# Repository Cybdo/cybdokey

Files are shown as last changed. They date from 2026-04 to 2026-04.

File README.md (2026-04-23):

# CybdoKey
A RP2354 based usb hardware authentication key, or anything else you can write firmware for ;)

render showing front and back of cybdokey

Cybdokey was made because yubikeys are too expensive and all the other options, including picofido on other devboards, were clunky. the user interaction button was tiny and hard to press, and depending on the board it was too big and/or needed an extra cable. Cybdokey was made to be a polished, compact FIDO key with capacative touch support.

**Note:** `bom.csv` is the LCSC parts list with working liks, whilst `overall-bom.csv` is an estimate of the overall project cost

## Zine Page / Poster

pdf in `assets/zine/Zine page.pdf`

Zine page

## Features
- RP2354-based development board
- Stacked 2MB flash storage
- onboard USB-A connector
- Capacative touch pad with shine-through red and blue LEDs
- exposed 3V3, GND, RESET and BOOTSEL
- 2 keyring/accessory mount holes
- Hand-solderable (in theory)
- tiny form factor!
render showing the backside of cybdokey

## Usage

Simply plug Cybdokey into your computer's USB-A port, and it will function similar to a yubikey. Passkeys and OTPs can be stored on it, and it supports human presence detection using the capacative touch pad. LED signals are identical to that of any other pico-fido key.

## Schematics


## PCB

|Front|Back|
|---|---|
| | |

## Firmware

See [https://github.com/cybdo/cybdokey-fw](https://github.com/cybdo/cybdokey-fw) for FIDO key firmware.

Firmware can be flashed on first boot, or by shorting the BOOTSEL jumper on the left side of the crystal, diagonally underneath the MCU, before booting.

CybdoKey is also compatiable with anything written for a RP2350/RP2354.

## Credits and Acknowledgements

 - [KiCad](https://www.kicad.org)
 - [Hack Club Fallout](https://fallout.hackclub.com)
 - [pcb2blender](https://github.com/30350n/pcb2blender)
 - [Blender](https://blender.org)
 - [MicroKey](https://github.com/Badbird5907/microkey)
 - [Pico FIDO](https://github.com/polhenarejos/pico-fido), forked to make [CybdoKey firmware](https://github.com/cybdo/cybdokey-fw)

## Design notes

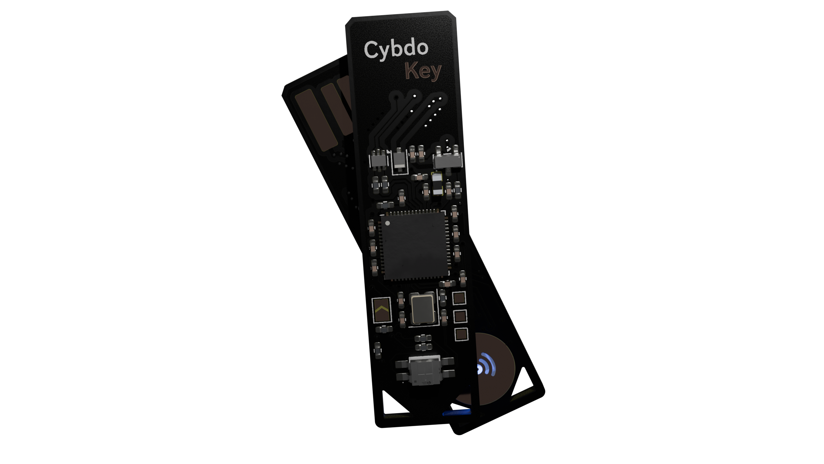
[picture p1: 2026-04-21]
assets/renders/front_and_back_nobg_1440p.png

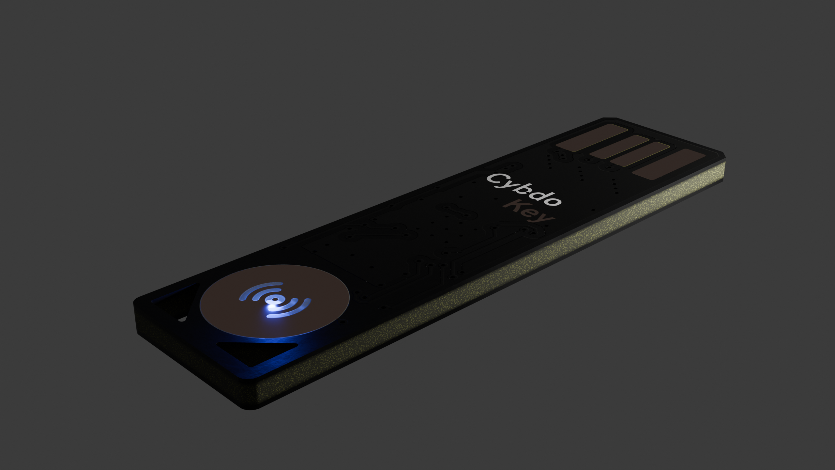
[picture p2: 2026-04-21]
assets/renders/back_1440p.png

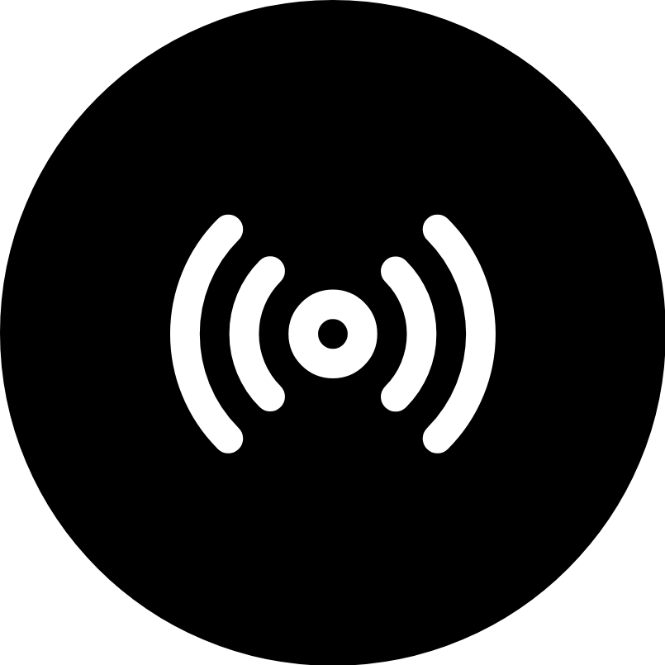
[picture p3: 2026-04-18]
assets/touchpad/touchpad.png

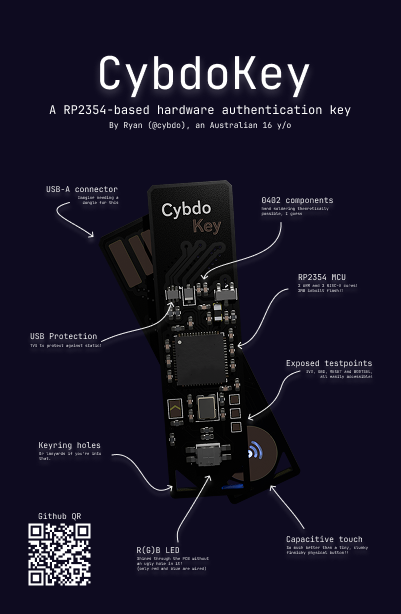
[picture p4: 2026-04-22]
assets/zine/Zine page.png

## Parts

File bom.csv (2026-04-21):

Index | LCSC# | MPN | Manufacturer | Package | Customer # | Description | RoHS | Quantity | MOQ | Multiple | Unit Price($) | Extended Price($) | Product Link
1 | C60474 | CC0402KRX7R7BB104 | YAGEO | 0402 | C7,C6,C8,C16,C12,C10,C17,C11,C9 | 100nF ±10% 16V Ceramic Capacitor X7R 0402 | yes | 100 | 100 | 100 | 0.0010 | 0.10 | https://www.lcsc.com/product-detail/C60474.html
2 | C191023 | 1N5819WS | Guangdong Hottech | SOD-323 | D1 | Diode 40V 1A Surface Mount SOD-323 | yes | 50 | 50 | 50 | 0.0106 | 0.53 | https://www.lcsc.com/product-detail/C191023.html
3 | C106235 | RC0402FR-071KL | YAGEO | 0402 | R6,R4 | 1kΩ 62.5mW 50V Thick Film Resistor ±100ppm/℃ ±1% 0402 Chip Resistor - Surface Mount RoHS | yes | 100 | 100 | 100 | 0.0008 | 0.08 | https://www.lcsc.com/product-detail/C106235.html
4 | C23733 | CL05A475MP5NRNC | Samsung Electro-Mechanics | 0402 | C18,C19,C5,C3,C4,C15 | 4.7uF ±20% 10V Ceramic Capacitor X5R 0402 | yes | 50 | 50 | 50 | 0.0060 | 0.30 | https://www.lcsc.com/product-detail/C23733.html
5 | C138021 | RC0402FR-0727RL | YAGEO | 0402 | R2,R1 | 27Ω ±1% 62.5mW 0402 Thick Film Resistor | yes | 100 | 100 | 100 | 0.0009 | 0.09 | https://www.lcsc.com/product-detail/C138021.html
6 | C138033 | RC0402FR-071ML | YAGEO | 0402 | R7 | 62.5mW 1MΩ 50V Thick Film Resistor ±100ppm/℃ ±1% 0402 Chip Resistor - Surface Mount RoHS | yes | 100 | 100 | 100 | 0.0009 | 0.09 | https://www.lcsc.com/product-detail/C138033.html
7 | C2906868 | FRC0402F33R0TS | FOJAN | 0402 | R3 | 33Ω ±1% 62.5mW 0402 Thick Film Resistor | yes | 100 | 100 | 100 | 0.0006 | 0.06 | https://www.lcsc.com/product-detail/C2906868.html
8 | C315248 | CL05A106MP5NUNC | Samsung Electro-Mechanics | 0402 | C2,C1 | 10uF ±20% 10V Ceramic Capacitor X5R 0402 | yes | 20 | 20 | 20 | 0.0092 | 0.18 | https://www.lcsc.com/product-detail/C315248.html
9 | C20625731 | ABM8-272-T3 | ABRACON | SMD3225-4P | Y1 | ±30ppm 10pF ±30ppm SMD3225-4P Crystals RoHS | yes | 10 | 5 | 5 | 0.2938 | 2.94 | https://www.lcsc.com/product-detail/C20625731.html
10 | C60490 | RC0402FR-0710KL | YAGEO | 0402 | R5 | 62.5mW 10kΩ 50V Thick Film Resistor ±100ppm/℃ ±1% 0402 Chip Resistor - Surface Mount RoHS | yes | 100 | 100 | 100 | 0.0008 | 0.08 | https://www.lcsc.com/product-detail/C60490.html
11 | C6851380 | AAA3528RBGS/08-09 | Kingbright | SMD3528-4P | D3 | 120° SMD3528-4P LED Indication - Discrete RoHS | yes | 1 | 1 | 1 | 1.7689 | 1.77 | https://www.lcsc.com/product-detail/C6851380.html
12 | C42411119 | AOTA-B201610S3R3-101-T | ABRACON | 0806 | L1 | 2.1A 3.3uH 115mΩ 2.4A Molded Inductor 0806 Fixed Inductors RoHS | yes | 5 | 5 | 5 | 0.2888 | 1.44 | https://www.lcsc.com/product-detail/C42411119.html
13 | C15999 | USBLC6-2P6 | ST | SOT-666-6 | U3 | 17VC Clamp 5A@8/20us Ipp ESD DIODE SOT-666-6 | yes | 5 | 5 | 5 | 0.2264 | 1.13 | https://www.lcsc.com/product-detail/C15999.html
14 | C112291 | RC0402FR-07220RL | YAGEO | 0402 | R9,R8 | 220Ω 62.5mW 50V Thick Film Resistor ±100ppm/℃ ±1% 0402 Chip Resistor - Surface Mount RoHS | yes | 100 | 100 | 100 | 0.0009 | 0.09 | https://www.lcsc.com/product-detail/C112291.html
15 | C41378174 | RP2354A | Raspberry Pi | QFN-60(7x7) | U1 | QFN-60(7x7) Microcontrollers RoHS | yes | 1 | 1 | 1 | 1.4929 | 1.49 | https://www.lcsc.com/product-detail/C41378174.html

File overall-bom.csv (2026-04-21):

Name | Supplier | Description | Cost Ea | Qty | Cost (USD)
PCB | AllPCB | 2mm black PCB (ALLPCB due to lower cost for 2mm boards) | 27 | 1 | 27
Components | LCSC | components, incl MOQ, see lcsc-bom.csv for details | 10.4 | 1 | 10.4
Components Shipping | LCSC | shipping and handling fee | 12.22 | 1 | 12.22
Stencil | JLCPCB | stencil from jlc because its cheaper | 7.11 | 1 | 7.11
Stencil shipping | JLCPCB | shipping for stencil | 15.51 | 1 | 15.51
 |  |  |  | TOTAL: | 72.24 | USD

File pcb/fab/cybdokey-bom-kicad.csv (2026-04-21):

Id | Designator | Footprint | Quantity | Designation | Supplier and ref
1 | C7,C6,C8,C16,C12,C10,C17,C11,C9 | C_0402_1005Metric_Pad0.74x0.62mm_HandSolder | 9 | 100nF
2 | D1 | D_SOD-323F | 1 | 1N5819WS
3 | R6,R4 | R_0402_1005Metric_Pad0.72x0.64mm_HandSolder | 2 | 1kR
4 | C18,C19,C5,C3,C4,C15 | C_0402_1005Metric_Pad0.74x0.62mm_HandSolder | 6 | 4.7uF
5 | R2,R1 | R_0402_1005Metric_Pad0.72x0.64mm_HandSolder | 2 | 27R
6 | R7 | R_0402_1005Metric_Pad0.72x0.64mm_HandSolder | 1 | 1MR
7 | R3 | R_0402_1005Metric_Pad0.72x0.64mm_HandSolder | 1 | 33R
8 | TP2 | TestPoint_Pad_1.0x1.0mm | 1 | run
9 | C2,C1 | C_0402_1005Metric_Pad0.74x0.62mm_HandSolder | 2 | 10uF
10 | Y1 | Crystal_SMD_Abracon_ABM8G-4Pin_3.2x2.5mm | 1 | ABM8-272-T3
11 | R5 | R_0402_1005Metric_Pad0.72x0.64mm_HandSolder | 1 | 10kR
12 | D3 | LED-SMD_4P-L3.2-W2.8_XZMDKCBDDG45S-9 | 1 | LED_RKBG
13 | TP4 | TestPoint_Pad_1.0x1.0mm | 1 | GND
14 | U1 | RP2350-QFN-60-1EP_7x7_P0.4mm_EP3.4x3.4mm_ThermalVias | 1 | RP2354_60QFN
15 | TP3 | TestPoint_Pad_1.0x1.0mm | 1 | 3V3
16 | L1 | INDC1608X95N | 1 | 3.3u
17 | U3 | SOT-666 | 1 | USBLC6-2P6
18 | R9,R8 | R_0402_1005Metric_Pad0.72x0.64mm_HandSolder | 2 | 220R
19 | U2 | SOT-23 | 1 | MCP1700x-300xxTT
20 | J1 | USB_A_PCB_Edge_receptacle | 1 | USB_A
21 | REF** | cybdokey | 1 | cybdokey

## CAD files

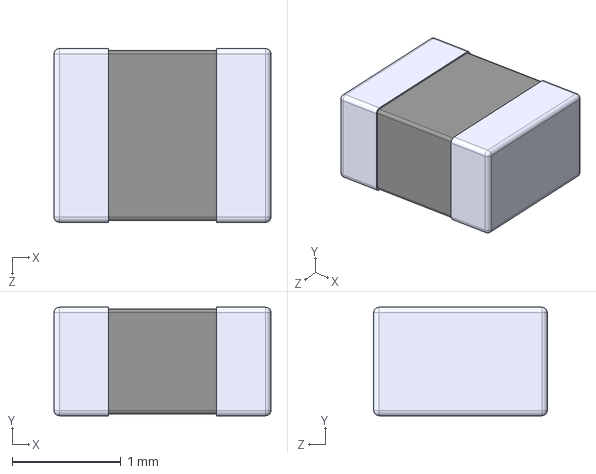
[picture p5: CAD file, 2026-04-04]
pcb/imports/ASMPH-0806-1R0M-T.step
2.00 x 1.00 x 1.60 mm

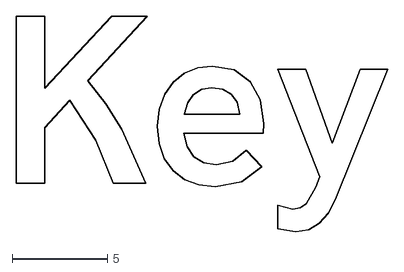
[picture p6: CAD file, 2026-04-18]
assets/cybdokey text/Key.dxf
19.4 x 11.3

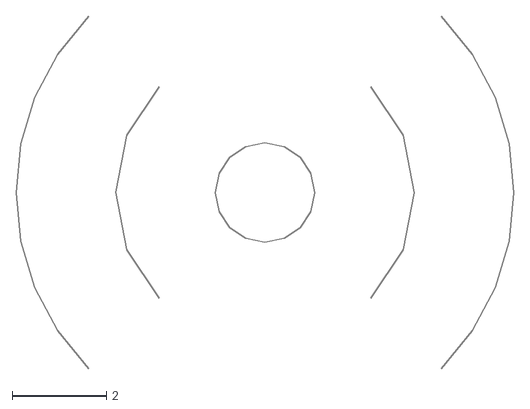
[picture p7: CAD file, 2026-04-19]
assets/touchpad/radio icon.dxf
10.6 x 7.48

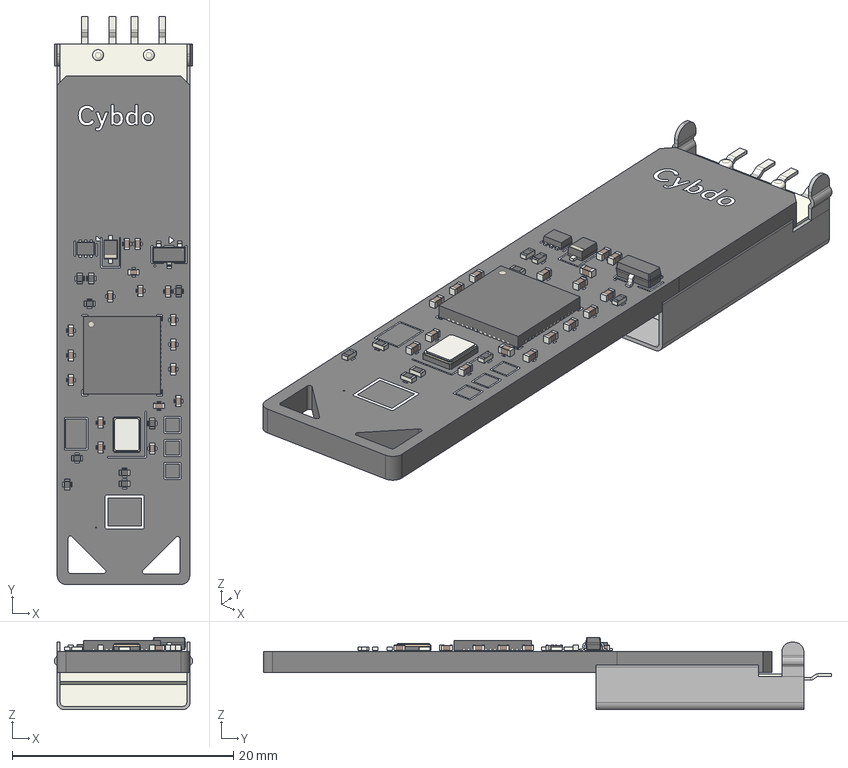
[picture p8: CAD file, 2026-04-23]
pcb/cybdokey.step
12.5 x 51.4 x 6.53 mm
C_0402_1005Metric x 17
D_SOD-323F
R_0402_1005Metric x 9
Crystal_SMD_Abracon_ABM8G-4Pin_3.2x2.5mm
QFN-56-1EP_7x7mm_P0.4mm_EP5.6x5.6mm
SOT-666
SOT-23
USB_A_CNCTech_1001-011-01101_Horizontal
cybdokey_silkscreen x 2
cybdokey_PCB

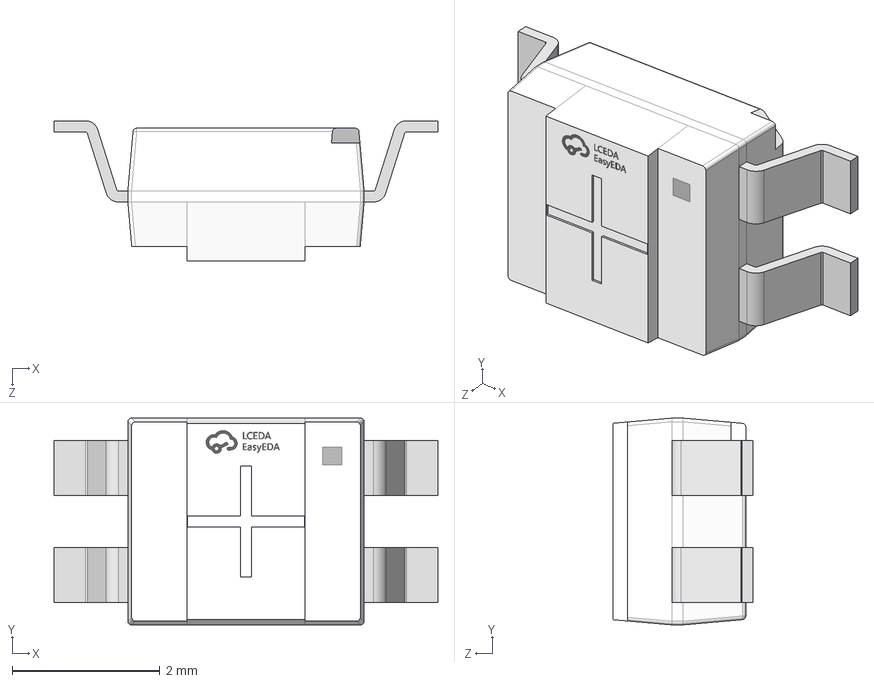
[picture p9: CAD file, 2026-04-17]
pcb/imports/LED-SMD_4P-L3.2-W2.8_XZMDKCBDDG45S-9.step
5.20 x 2.80 x 1.90 mm

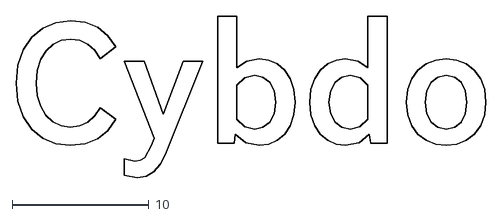
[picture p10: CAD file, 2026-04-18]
assets/cybdokey text/Cybdo.dxf
34.4 x 11.8

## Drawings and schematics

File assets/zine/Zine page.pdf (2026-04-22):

# A RP2354-based hardware authentication key

# CybdoKey

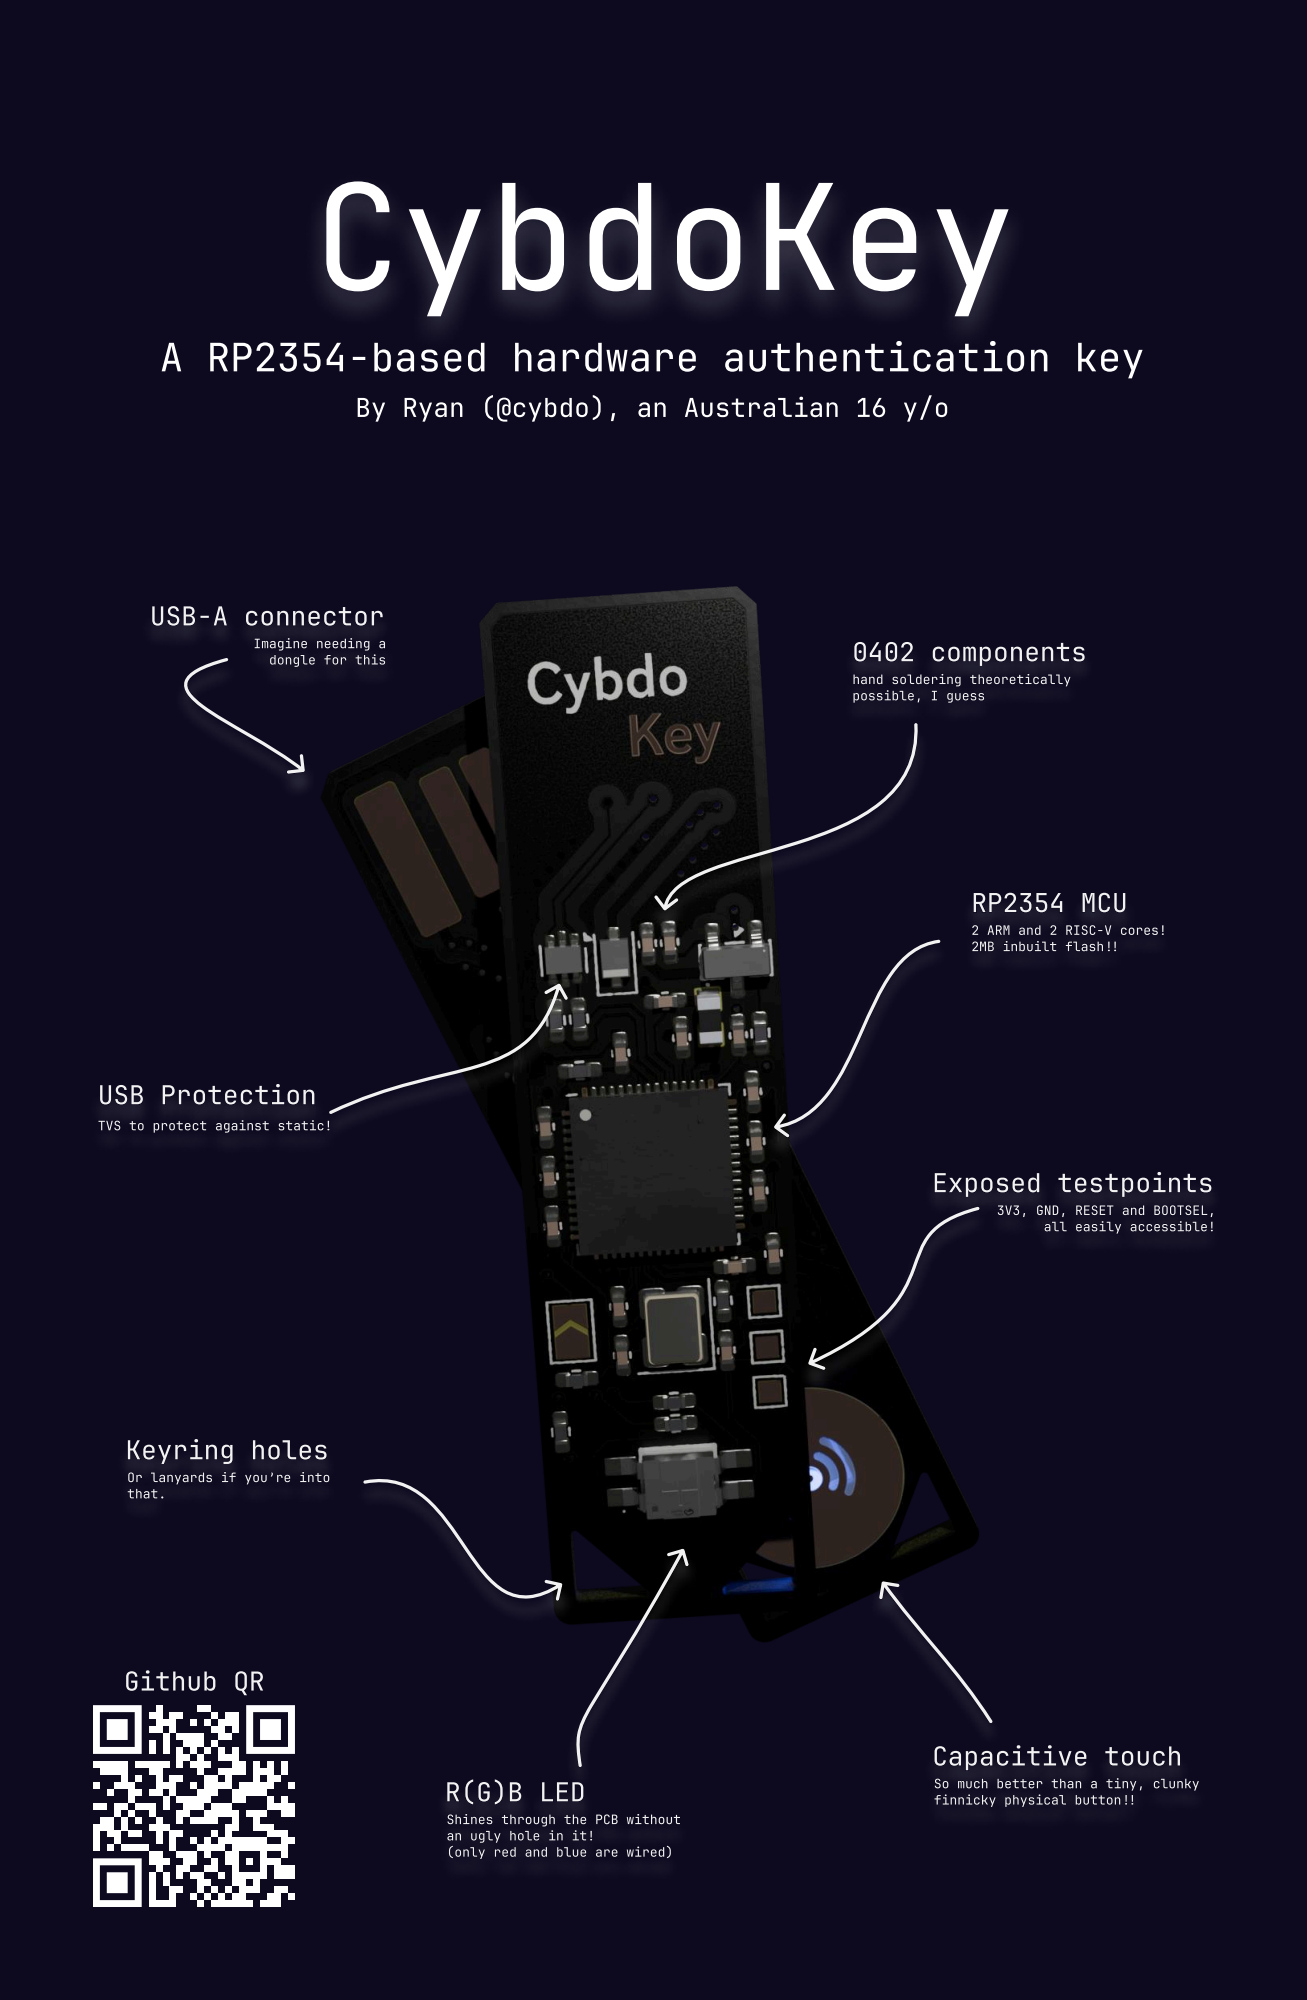
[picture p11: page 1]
USB-A connector; Imagine needing a; dongle for this; 0402 components; possible, I guess; RP2354 MCU; USB Protection; Exposed testpoints; Keyring holes; Github QR; R(G)B LED; Capacitive touch

By Ryan (@cybdo), an Australian 16 y/o

hand soldering theoretically

2 ARM and 2 RISC-V cores!
2MB inbuilt flash!!

TVS to protect against static!

3V3, GND, RESET and BOOTSEL,

all easily accessible!

Or lanyards if you’re into
that.

So much better than a tiny, clunky
finnicky physical button!!

Shines through the PCB without
an ugly hole in it!
(only red and blue are wired)

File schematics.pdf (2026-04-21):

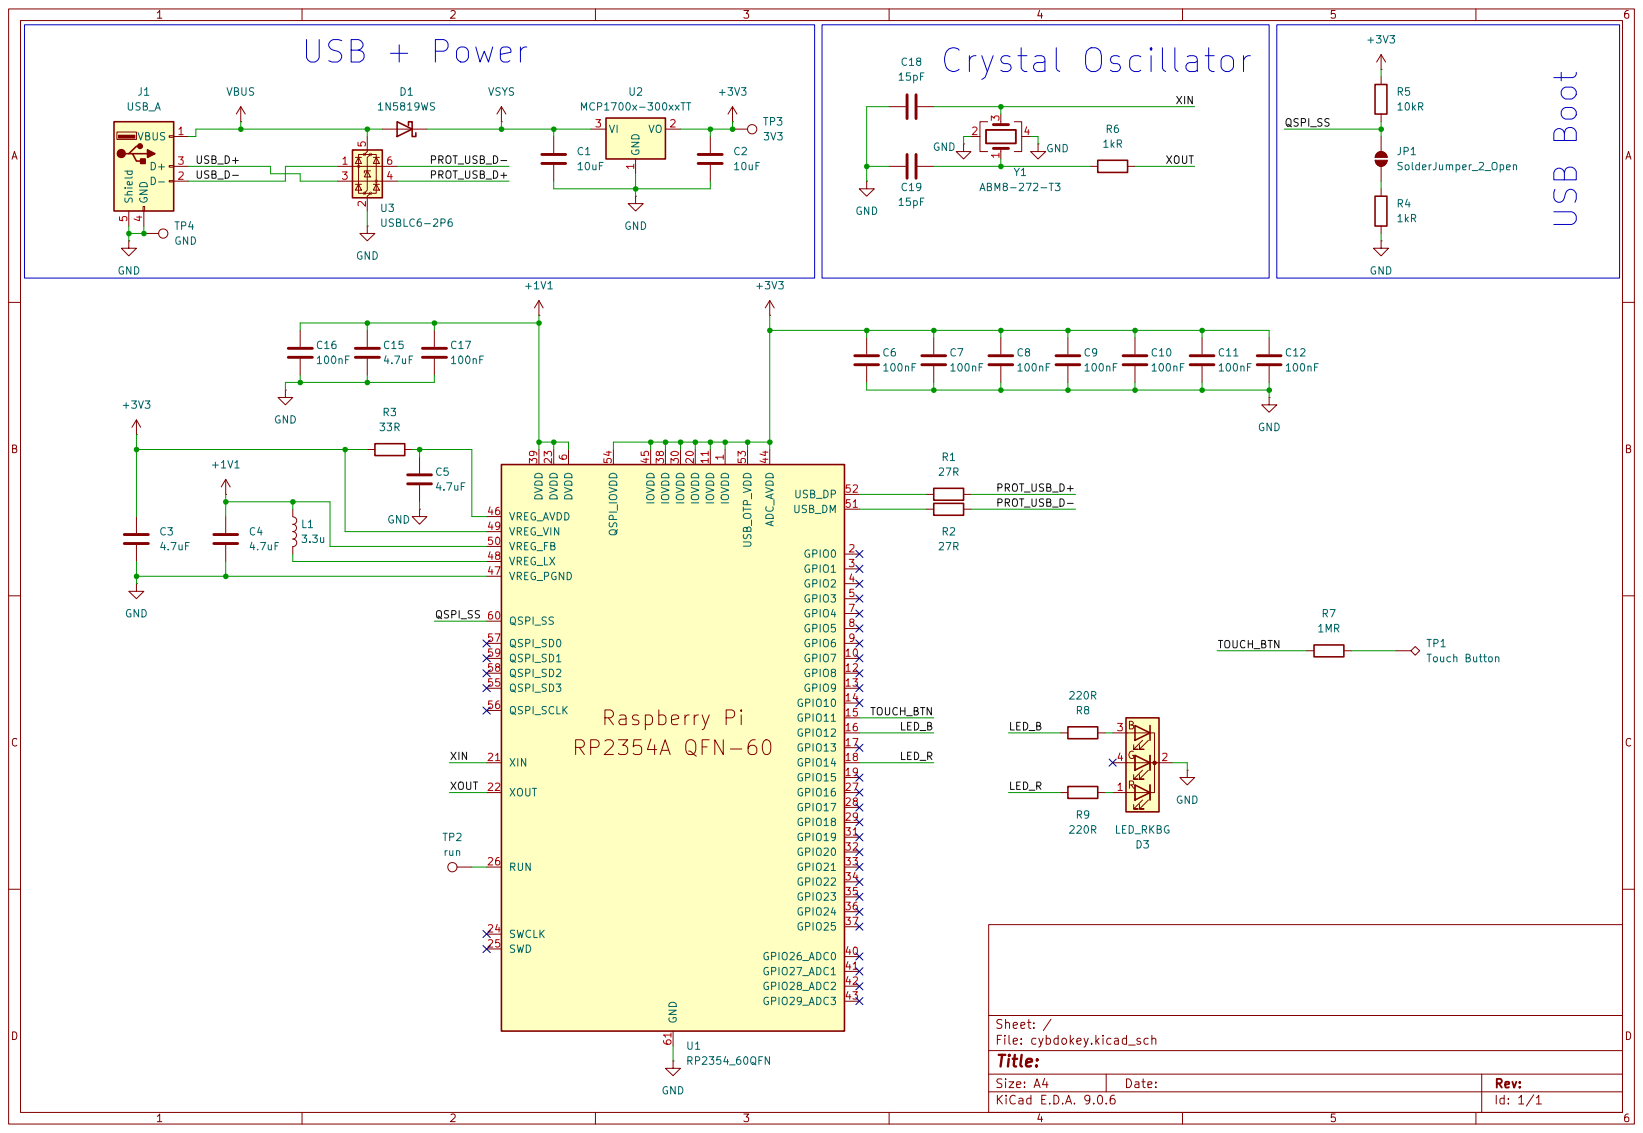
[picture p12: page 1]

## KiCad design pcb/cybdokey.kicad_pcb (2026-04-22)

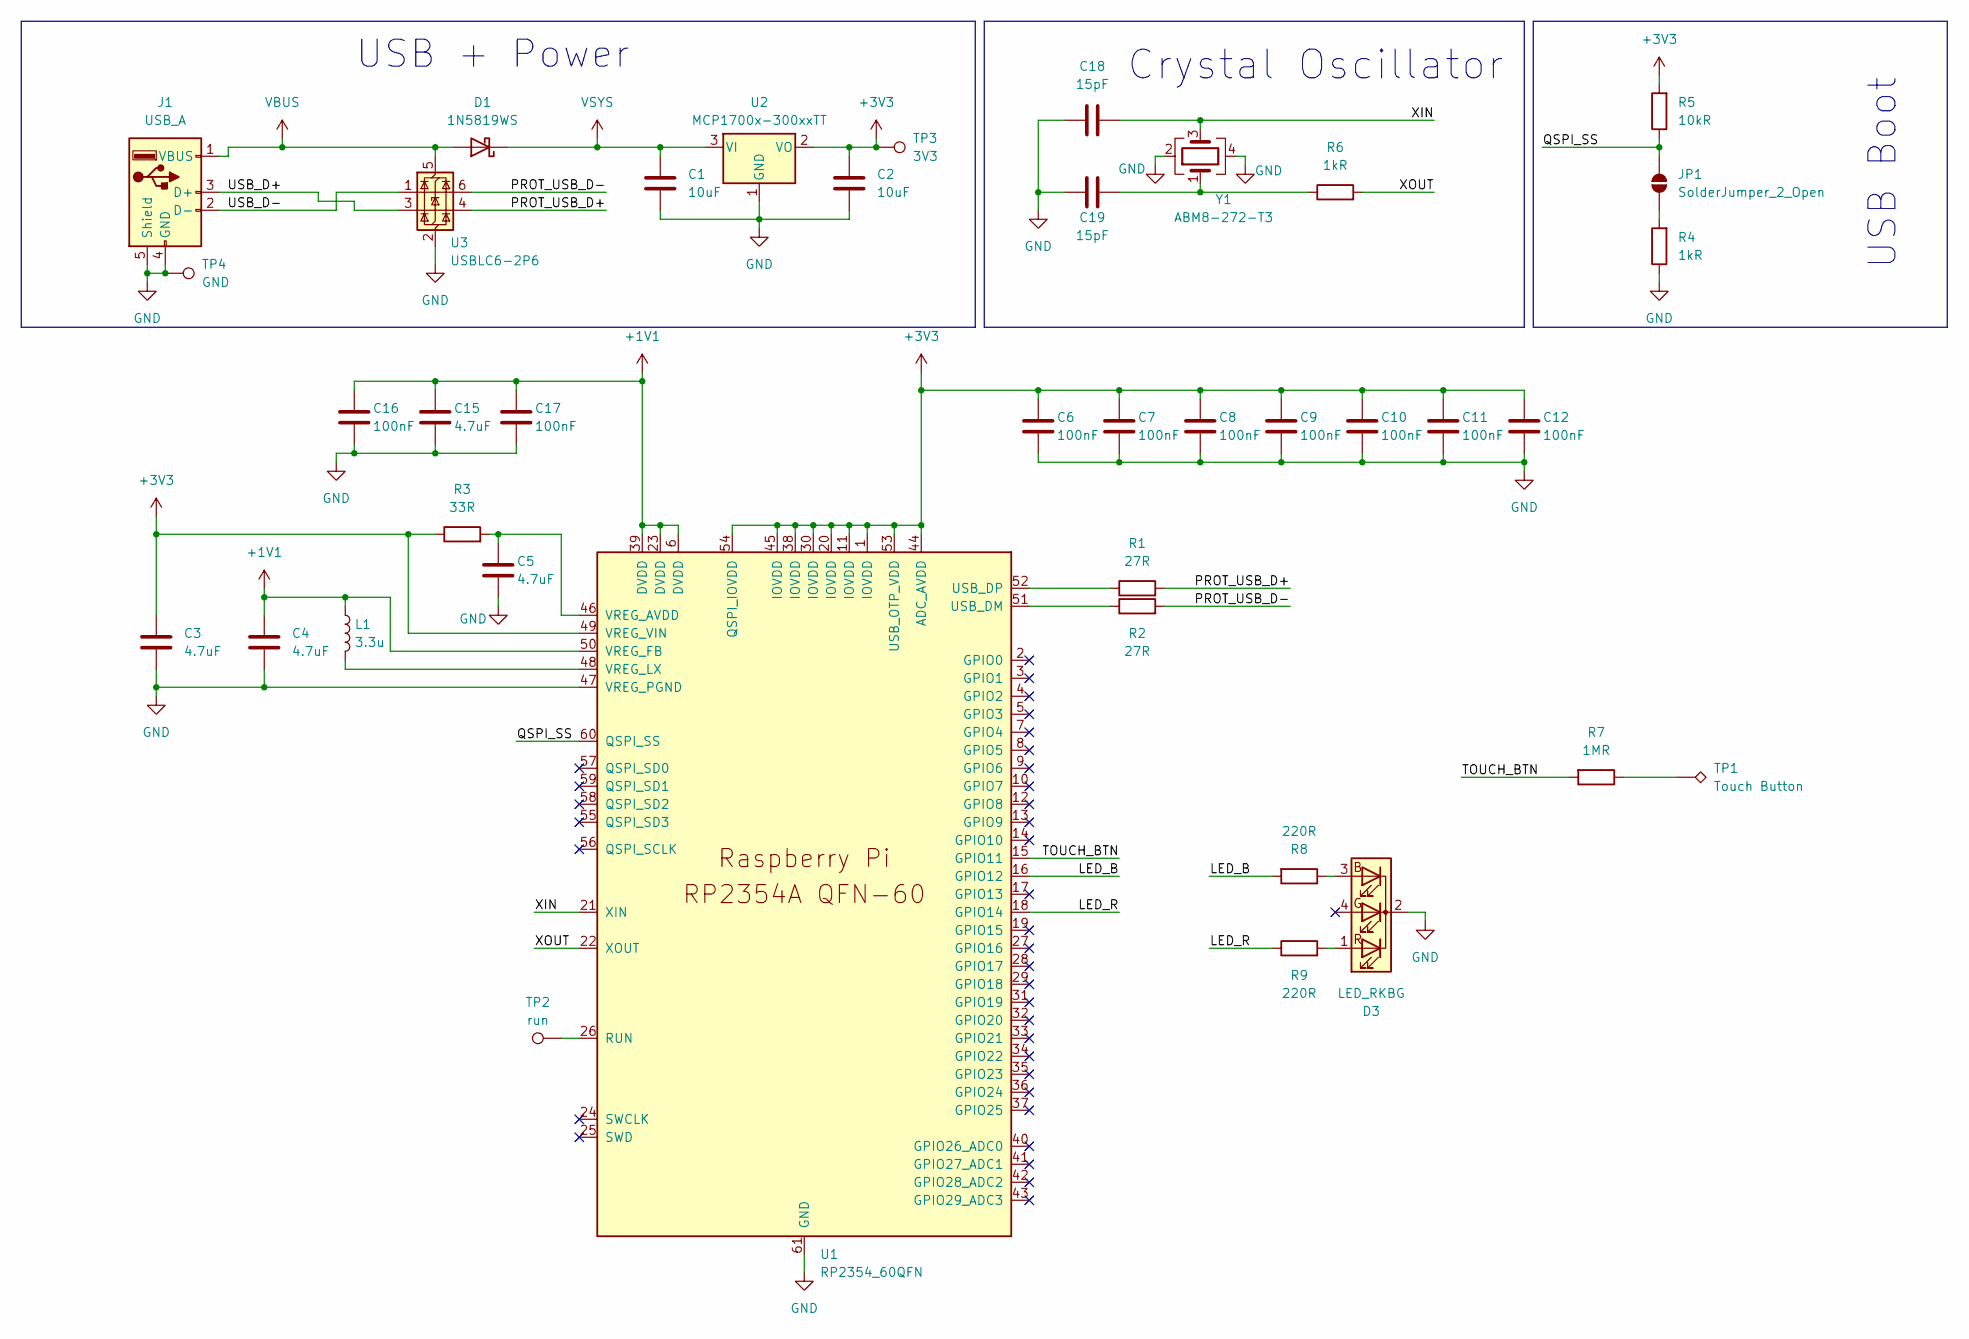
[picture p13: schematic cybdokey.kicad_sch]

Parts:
C1, C2: 10uF; C_0402_1005Metric_Pad0.74x0.62mm_HandSolder
C3, C4, C5, C15: 4.7uF; C_0402_1005Metric_Pad0.74x0.62mm_HandSolder
C6, C7, C8, C9, C10, C11, C12, C16, C17: 100nF; C_0402_1005Metric_Pad0.74x0.62mm_HandSolder
C18, C19: 15pF; C_0402_1005Metric_Pad0.74x0.62mm_HandSolder
D1: 1N5819WS; D_SOD-323F
D3: LED_RKBG; LED-SMD_4P-L3.2-W2.8_XZMDKCBDDG45S-9
J1: USB_A; USB_A_PCB_Edge_receptacle
JP1: SolderJumper_2_Open; SolderJumper-2_P1.3mm_Open_TrianglePad1.0x1.5mm
L1: 3.3u; INDC1608X95N
R1, R2: 27R; R_0402_1005Metric_Pad0.72x0.64mm_HandSolder
R3: 33R; R_0402_1005Metric_Pad0.72x0.64mm_HandSolder
R4, R6: 1kR; R_0402_1005Metric_Pad0.72x0.64mm_HandSolder
R5: 10kR; R_0402_1005Metric_Pad0.72x0.64mm_HandSolder
R7: 1MR; R_0402_1005Metric_Pad0.72x0.64mm_HandSolder
R8, R9: 220R; R_0402_1005Metric_Pad0.72x0.64mm_HandSolder
TP1: Touch Button; touchpad
TP2: run; TestPoint_Pad_1.0x1.0mm
TP3: 3V3; TestPoint_Pad_1.0x1.0mm
TP4: GND; TestPoint_Pad_1.0x1.0mm
U1: RP2354_60QFN; RP2350-QFN-60-1EP_7x7_P0.4mm_EP3.4x3.4mm_ThermalVias
U2: MCP1700x-300xxTT; SOT-23
U3: USBLC6-2P6; SOT-666
Y1: ABM8-272-T3; Crystal_SMD_Abracon_ABM8G-4Pin_3.2x2.5mm

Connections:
+1V1: C4.1, C15.1, C16.1, C17.1, L1.1, U1.6 (DVDD), U1.23 (DVDD), U1.39 (DVDD), U1.50 (VREG_FB)
+3V3: C2.1, C3.1, C6.1, C7.1, C8.1, C9.1, C10.1, C11.1, C12.1, R3.1, R5.2, TP3.1, U1.1 (IOVDD), U1.11 (IOVDD), U1.20 (IOVDD), U1.30 (IOVDD), U1.38 (IOVDD), U1.44 (ADC_AVDD), U1.45 (IOVDD), U1.49 (VREG_VIN), U1.53 (USB_OTP_VDD), U1.54 (QSPI_IOVDD), U2.2 (VO)
/LED_B: R8.2, U1.16 (GPIO12)
/LED_R: R9.1, U1.18 (GPIO14)
/PROT_USB_D+: R1.2, U3.4 (I/O2)
/PROT_USB_D-: R2.2, U3.6 (I/O1)
/QSPI_SS: JP1.2 (B), R5.1, U1.60 (QSPI_SS)
/TOUCH_BTN: R7.2, U1.15 (GPIO11)
/USB_D+: J1.3 (D+), U3.3 (I/O2)
/USB_D-: J1.2 (D-), U3.1 (I/O1)
/XIN: C18.2, U1.21 (XIN), Y1.3
/XOUT: R6.2, U1.22 (XOUT)
GND: C1.2, C2.2, C3.2, C4.2, C5.2, C6.2, C7.2, C8.2, C9.2, C10.2, C11.2, C12.2, C15.2, C16.2, C17.2, C18.1, C19.2, D3.2 (K), J1.4 (GND), J1.5 (Shield), R4.1, TP4.1, U1.47 (VREG_PGND), U1.61 (GND), U2.1 (GND), U3.2 (GND), Y1.2, Y1.4
unnamed: C19.1, R6.1, Y1.1
unnamed: D3.3 (BA), R8.1
unnamed: D3.1 (RA), R9.2
unnamed: JP1.1 (A), R4.2
unnamed: R7.1, TP1.1
unnamed: TP2.1, U1.26 (RUN)
unnamed: R2.1, U1.51 (USB_DM)
unnamed: R1.1, U1.52 (USB_DP)
unnamed: C5.1, R3.2, U1.46 (VREG_AVDD)
unnamed: L1.2, U1.48 (VREG_LX)
VBUS: D1.2 (A), J1.1 (VBUS), U3.5 (VBUS)
VSYS: C1.1, D1.1 (K), U2.3 (VI)

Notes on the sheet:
Crystal Oscillator
USB Boot
USB + Power

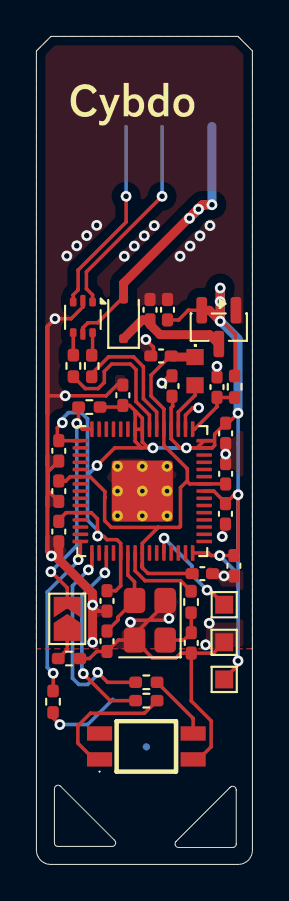
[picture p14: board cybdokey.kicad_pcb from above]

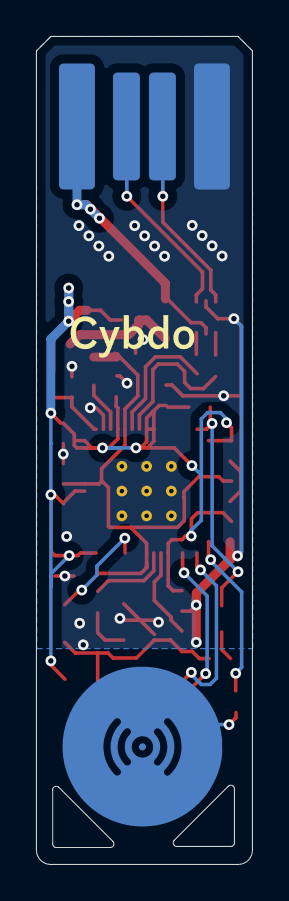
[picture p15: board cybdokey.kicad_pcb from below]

Board: 2 copper layers, 12.0 x 46.0 mm, 39 parts (2 on the bottom side), 25 nets.

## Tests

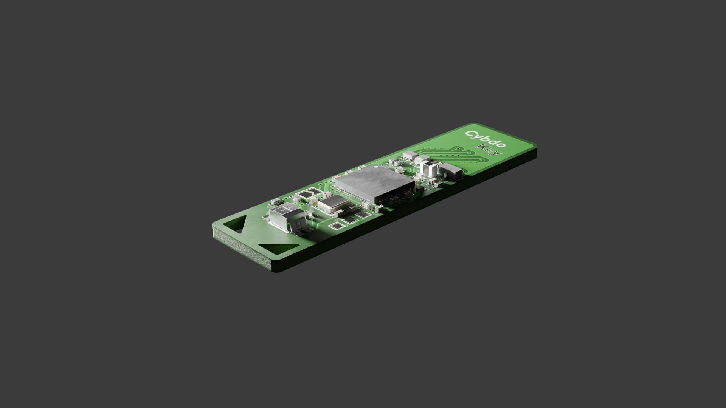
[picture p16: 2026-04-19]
assets/renders/test render.png

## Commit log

2026-04-04 finished schematics
    [cybdokey.kicad_pcb, cybdokey.kicad_sch]
2026-04-04 started routing
    [ASMPH-0806-1R0M-T.step, cybdokey.kicad_pcb, cybdokey.kicad_sch]
2026-04-05 more routing
    [cybdokey.kicad_pcb, cybdokey.kicad_sch]
2026-04-05 routing done... for now
    [cybdokey.kicad_pcb, cybdokey.kicad_sch]
2026-04-07 cleaned up routing
    [cybdokey.kicad_pcb, cybdokey.kicad_sch]
2026-04-07 cleaned up routing the second
    [cybdokey.kicad_pcb]
2026-04-17 changed LED, moving back to windows
    [LED-SMD_4P-L3.2-W2.8_XZMDKCBDDG45S-9.step, cybdokey.kicad_pcb, cybdokey.kicad_sch]
2026-04-18 add new touch button footprint and add some branding
    [Cybdo.dxf, Key.dxf, cybdokey.kicad_pcb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]
2026-04-18 add cybdokey branding
    i forgor
    [cybdokey.kicad_pcb]
2026-04-19 polishing, started with some renders
    [cybdokey.kicad_pcb, cybdokey.kicad_sch, radio icon.dxf]
2026-04-21 render stuff, add zine page
    [cybdokey.kicad_pcb]
2026-04-21 make production files, add bom
    [cybdokey-B_Cu.gbr, cybdokey-B_Mask.gbr, cybdokey-B_Paste.gbr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]
2026-04-21 csvs were gitignored oops
    [bom.csv, cybdokey-bom-kicad.csv, lcsc-bom.csv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]
2026-04-22 fix zine page, fix touchpad shinethrouhg window area
    [cybdokey.kicad_pcb]
